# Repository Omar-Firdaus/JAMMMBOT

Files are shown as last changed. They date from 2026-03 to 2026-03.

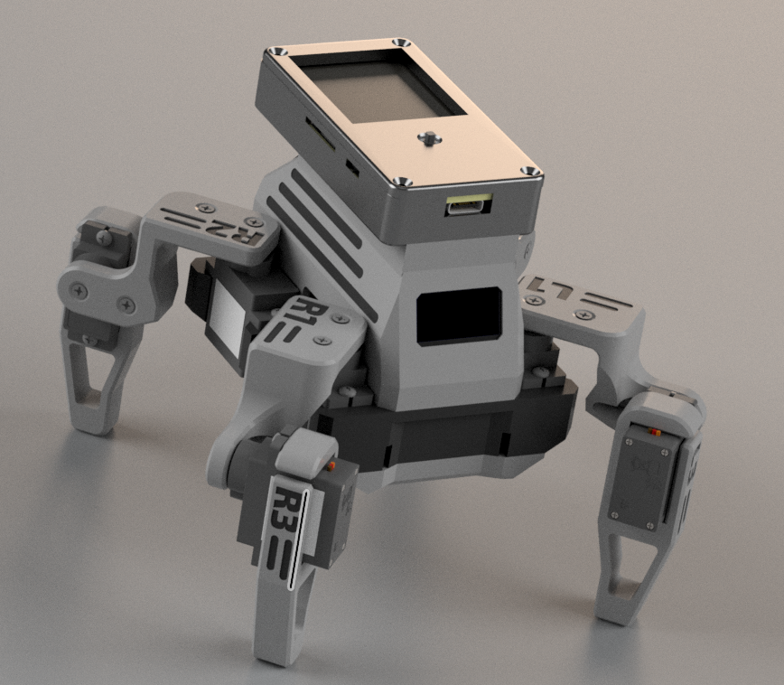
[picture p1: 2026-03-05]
Renders/Screenshot 2026-03-04 at 9.39.10 PM.png

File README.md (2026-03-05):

# JAMMMBOT

Before anything: huge shoutout to Dorian Todd and JustCallMeKoko, their work is the foudnation for this project and I couldn't have done any of this without their repos and guides.

Description: A quadrupedal robot that will detect nearby Wi-Fi devices, disrupt targeted connections, generate numerous spoofed networks, and overwhelm or mislead wireless scanning tools. Built for educational purposes.

Why I made this: I wanted to build a quadrapedal robot that can crawl, but also wanted to make it special in someway. So, I attached hacking hardware so it can penetrate test networks and do other cool things including but not limited to: staging deauthentication attacks, beacon spam, making fake wifi logins to capture credentials, run packet injections, bluetooth spam, and impersonate SSIDs.

Pictures:

Full Robot CAD
Screenshot 2026-03-04 at 9 39 10 PM
Screenshot 2026-03-05 at 9 21 15 AM

PCB for Power Distrubution
Screenshot 2026-03-05 at 9 07 09 AM

Hacking Board
Screenshot 2026-03-05 at 9 25 23 AM

BOM for Entire Project
| Name | Purpose | Cost (USD) | Qty | Total  |
| --- | --- | --- | --- | --- |
| Power distribution board + components | Powering all components | $29.00 | 1 | $29.00 |
| Filament | 3D printed robot frame | $13.99 | 1 | $13.99 |
| Soldering iron kit | Assembly of electronics | $9.99 | 1 | $9.99  |
| Hacking Board PCB + components | ESP32 control electronics | $18.00 | 1 | $18.00 |
| Control PCB Components (LCSC BOM) | All SMD parts for ESP32 board | $6.64 | 1 | $6.64  |
| M2 screw kit | Structural assembly | $6.55 | 1 | $6.55  |
| XT30 female pigtail | Battery connection | $3.50 | 2 | $7.00  |
| 2-slot 10440 Li-ion charger | Charging battery cells | $9.99 | 1 | $9.99  |
| 10440 Li-ion cells | Robot power supply | $2.49 | 4 | $9.96  |
| AAA holder | Battery mounting | $1.59 | 4 | $6.36  |
| Small zip ties | Cable management | $6.98 | 1 | $6.98  |
| 30AWG silicone wire kit | Dense electronics wiring | $10.09 | 1 | $10.09 |
| 22AWG silicone wire kit | Power wiring | $9.99 | 1 | $9.99  |
| Rocker power switch | Main system power | $0.59 | 5 | $2.95  |
| 0.96" SSD1306 OLED | Robot face display | $5.00 | 2 | $10.00 |
| MG90 Servos | Quadruped locomotion | $2.99 | 8 | $23.92 |

BOM for Power Distrubution PCB
| ID | Component | Designators | Footprint | Qty | Manufacturer Part | Manufacturer | Supplier | Supplier Part | Unit Price |
| -- | --- | --- | --- | --- | --- | --- | --- | --- | --- |
| 1  | 22 nF Capacitor | C3, C9, C11 | C0603 | 3 | CL10B223KB8NNNC | Samsung | LCSC | C21122 | $0.004 |
| 2  | 100 nF Capacitor | C4, C8, C10 | C0603 | 3 | CC0603KRX7R9BB104 | Yageo | LCSC | C14663 | $0.002 |
| 3  | 10 nF Capacitor | C5 | C0603 | 1 | C0603B103M500NT | Torch | LCSC | C17702744 | $0.005 |
| 4  | 3.3 µH Inductor | L1 | IND-SMD L7.3-W6.6 | 1 | MHCI06030-3R3M-S8 | Chilisin | LCSC | C285713 | $0.147 |
| 5  | Red LED | LED1 | LED0603-RD | 1 | KT-0603R | KENTO | LCSC | C2286 | $0.007 |
| 6  | 5.1 kΩ Resistor | R1, R5 | R0603 | 2 | 0603WAF5101T5E | UNI-ROYAL | LCSC | C23186 | $0.001 |
| 7  | 56 kΩ Resistor | R2 | R0603 | 1 | 0603WAF5602T5E | UNI-ROYAL | LCSC | C23206 | $0.001 |
| 8  | 10 kΩ Resistor | R3, R4, R8, R9 | R0603 | 4 | RCT0310KJLF | HKR | LCSC | C177337 | — |
| 9  | 3.5 mm 2-Pin Screw Terminal | 5-12V | ScrewTerm-3.5mm-2Pin | 1 | 1984617 | Phoenix Contact | Digi-Key | — | — |
| 10 | JST-XH 4-Pin Connector | JST-XH | JST-XH-4PIN-2.5 | 1 | — | — | — | — | — |
| 11 | Tactile Switch | RESET, BOOT | KEY-SMD L4.0-W3.0 | 2 | HX 3x4x2-2P-1.6N | Hanxia | LCSC | C49234124 | $0.02 |
| 12 | Large Solder Pad | U5, U7 | SOLDERPAD LG | 2 | — | — | — | — | — |
| 13 | 1 µF Capacitor | C1 | C0805 | 1 | AC0805KKX7R9BB105 | Yageo | LCSC | C726584 | $0.035 |
| 14 | 470 µF Capacitor | C7 | Large SMD Cap | 1 | XT470UF25V90RV0111 | KNSCHA | LCSC | C3445244 | $0.128 |
| 15 | Schottky Diode SS34 | D1, D2 | SMA | 2 | SS34 | MDD | LCSC | C8678 | $0.03 |
| 16 | 3-Pin Headers | P1–P8 | 2.54mm Pin Header | 8 | HDR1X8-2.54 | BOOMELE | LCSC | C27438 | $0.088 |
| 17 | ESP32-S3 Module | U1 | ESP32-S3-WROOM-1 | 1 | ESP32-S3-WROOM-1-N16R8 | Espressif | LCSC | C2913202 | $5.613 |
| 18 | 3.3 V LDO Regulator | U2 | SOT-223-3 | 1 | AMS1117-3.3 | AMS | LCSC | C6186 | $0.197 |
| 19 | Buck Converter IC | U3 | SOT-23-6 | 1 | MSTPS563200DDCR | MSKSEMI | LCSC | C49208508 | $0.177 |
| 20 | 10 µF Capacitor | U4 | SMD Electrolytic | 1 | RST10UF25V014 | KNSCHA | LCSC | C4747969 | $0.025 |

BOM For Hacking ESP PCB
| ID | Component | Designator | Package | Qty | Manufacturer Part | Supplier | Unit Price | Total  |
| -- | --- | --- | --- | --- | --- | --- | --- | --- |
| 1  | 22nF capacitor | C3, C9, C11 | 0603 | 3 | CL10B223KB8NNNC | LCSC | $0.004 | $0.012 |
| 2  | 100nF capacitor | C4, C8, C10 | 0603 | 3 | CC0603KRX7R9BB104 | LCSC | $0.002 | $0.006 |
| 3  | 10nF capacitor | C5 | 0603 | 1 | C0603B103M500NT | LCSC | $0.005 | $0.005 |
| 4  | 3.3uH inductor | L1 | SMD | 1 | MHCI06030-3R3M-S8 | LCSC | $0.147 | $0.147 |
| 5  | Red LED | LED1 | 0603 | 1 | KT-0603R | LCSC | $0.007 | $0.007 |
| 6  | 5.1kΩ resistor | R1, R5 | 0603 | 2 | 0603WAF5101T5E | LCSC | $0.001 | $0.002 |
| 7  | 56kΩ resistor | R2 | 0603 | 1 | 0603WAF5602T5E | LCSC | $0.001 | $0.001 |
| 8  | 10kΩ resistor | R3, R4, R8, R9 | 0603 | 4 | RCT0310KJLF | LCSC | ~$0.001 | $0.004 |
| 9  | 3.5mm 2-pin screw terminal | 5-12V input | Through-hole | 1 | 1984617 | Digi-Key | ~$0.50 | $0.50  |
| 10 | JST-XH 4-pin connector | JST-XH | 2.5mm | 1 | JST-XH-4P | LCSC | ~$0.10 | $0.10  |
| 11 | Tactile switch | RESET, BOOT | SMD | 2 | HX 3x4x2-2P | LCSC | $0.02 | $0.04  |
| 12 | Solder pads | U5, U7 | PCB pad | 2 | — | — | — | — |
| 13 | 1µF capacitor | C1 | 0805 | 1 | AC0805KKX7R9BB105 | LCSC | $0.035 | $0.035 |
| 14 | 470µF capacitor | C7 | SMD electrolytic | 1 | XT470UF25V90RV0111 | LCSC | $0.128 | $0.128 |
| 15 | SS34 Schottky diode | D1, D2 | SMA | 2 | SS34 | LCSC | $0.030 | $0.060 |
| 16 | 3-pin headers | P1-P8 | 2.54mm | 8 | HDR1X8-2.54 | LCSC | $0.088 | $0.704 |
| 17 | ESP32-S3-WROOM-1-N16R8 | U1 | RF module | 1 | ESP32-S3-WROOM-1-N16R8 | LCSC | $5.613 | $5.613 |
| 18 | AMS1117-3.3 LDO | U2 | SOT-223 | 1 | AMS1117-3.3 | LCSC | $0.197 | $0.197 |
| 19 | Buck converter IC | U3 | SOT-23-6 | 1 | MSTPS563200DDCR | LCSC | $0.177 | $0.177 |
| 20 | 10µF capacitor | U4 | SMD | 1 | RST10UF25V014 | LCSC | $0.025 | $0.025 |

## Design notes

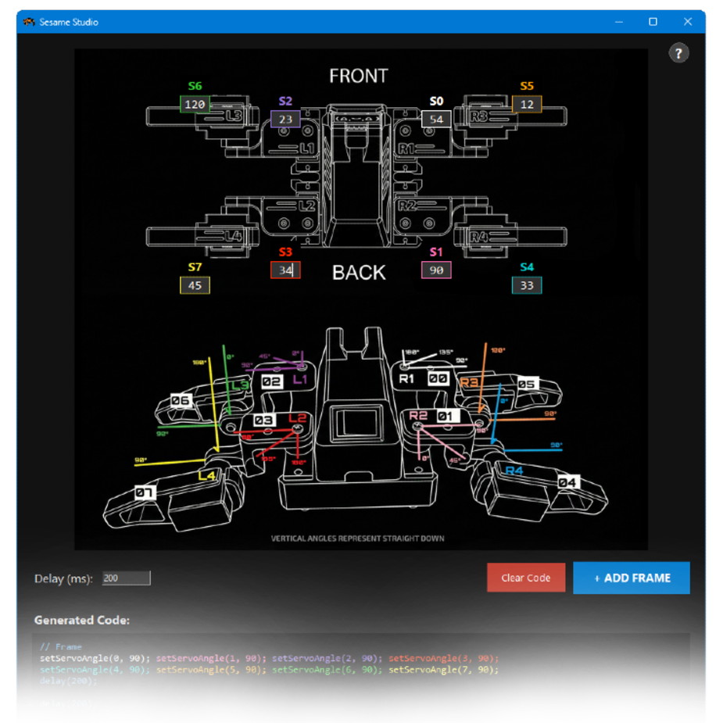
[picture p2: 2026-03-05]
Software/assets/sesamestudio-preview.png

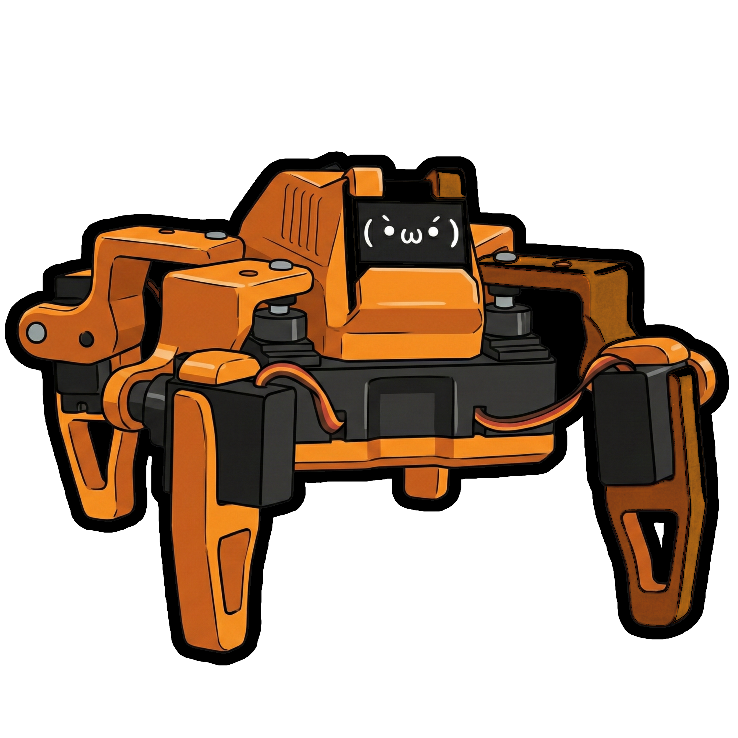
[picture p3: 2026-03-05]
Software/assets/sesame-sticker2.png

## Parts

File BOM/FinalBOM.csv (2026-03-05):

Name | Purpose | Cost (USD) | Qty | Total | Purchase Link
Power distribution board + components | Powering all components | 29.00 | 1 | 29.00 | https://www.pcbway.com/
Filament | 3D printed robot frame | 13.99 | 1 | 13.99 | https://www.amazon.com/ELEGOO-Filament-Dimensional-Accuracy-Cardboard/dp/B0BM739JRF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
Soldering iron kit | Assembly of electronics | 9.99 | 1 | 9.99 | https://www.amazon.com/Soldering-Adjustable-Temperature-356-932%E2%84%89-Electronics/dp/B0FP24CFB9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
Hacking Board PCB + components | ESP32 control electronics | 18.00 | 1 | 18.00 | https://jlcpcb.com/
Control PCB Components (LCSC BOM) | All SMD parts for ESP32 board | 6.64 | 1 | 6.64 | https://jlcpcb.com/
M2 screw kit | Structural assembly | 6.55 | 1 | 6.55 | https://www.amazon.com/Tapping-Woodworking-Fastener-Drilling-Assortment/dp/B0C5JVC6Z3
XT30 female pigtail | Battery connection | 3.50 | 2 | 7.00 | https://www.amazon.com/Padarsey-Connector-Female-Housing-Silicon/dp/B07CZDQT4T?sp_csd=d2lkZ2V0TmFtZT1zcF9hdGY
2-slot 10440 Li-ion charger | Charging battery cells | 9.99 | 1 | 9.99 | https://www.amazon.com/Battery-Bay-Charging-Universal-Batteries/dp/B0FW3JXCMS?sp_csd=d2lkZ2V0TmFtZT1zcF9hdGY
10440 Li-ion cells | Robot power supply | 2.49 | 4 | 9.96 | https://www.amazon.com/Rechargeable-Battery-JESSPOW-Batteries-Flashlight/dp/B08H4RC1Y5
AAA holder | Battery mounting | 1.59 | 4 | 6.36 | https://www.amazon.com/LAMPVPATH-Battery-Holder-Leads-Wires/dp/B08DR6L8F8/ref=sr_1_3?sr=8-3
Small zip ties | Cable management | 6.98 | 1 | 6.98 | https://www.amazon.com/gp/aw/d/B08TVLYB3Q/?aaxitk=bb1635f0ea64a6ea0029127a073b7fc4&hsa_cr_id=0
30AWG silicone wire kit | Dense electronics wiring | 10.09 | 1 | 10.09 | https://www.amazon.com/Fermerry-Silicone-Colors-Flexible-Stranded/dp/B089CXFH4H/ref=sr_1_7?sr=8-7
22AWG silicone wire kit | Power wiring | 9.99 | 1 | 9.99 | https://www.amazon.com/Stranded-Silicone-Electrical-32-8ft-Automotive/dp/B0DK571MVD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
Rocker power switch | Main system power | 0.59 | 5 | 2.95 | https://www.amazon.com/Rierdge-Household-Appliances-Industrial-Equipment/dp/B0F5BFYZSY
0.96 inch SSD1306 OLED | Robot face display | 5.00 | 2 | 10.00 | https://www.amazon.com/Wishiot-Display-Self-Luminous-Compatible-Raspberry/dp/B0D1BWY9Z8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
MG90 Servos | Quadruped locomotion | 2.99 | 8 | 23.92 | https://www.amazon.com/Beffkkip-Helicopter-Servos-Arduino-Project/dp/B01JY3H4MA

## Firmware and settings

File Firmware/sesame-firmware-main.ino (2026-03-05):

#include <WiFi.h>
#include <WebServer.h>
#include <DNSServer.h>
#include <ESPmDNS.h>
#include <Wire.h>
#include <ESP32Servo.h>
#include <Adafruit_GFX.h>
#include <Adafruit_SSD1306.h>
#include "face-bitmaps.h"
#include "movement-sequences.h"
#include "captive-portal.h"

// --- Access Point Configuration ---
// This is the network the Robot will create
#define AP_SSID  "Sesame-Controller-BETA"
#define AP_PASS  "12345678" // Must be at least 8 characters

// --- Station Mode Configuration (Optional) ---
// Set these to connect to your home/office WiFi network
// Leave NETWORK_SSID empty to disable station mode
#define NETWORK_SSID ""  // Your WiFi network name
#define NETWORK_PASS ""  // Your WiFi password
#define ENABLE_NETWORK_MODE false  // Set to true to enable network connection attempts

#define SCREEN_WIDTH 128
#define SCREEN_HEIGHT 64
#define OLED_RESET -1
#define OLED_I2C_ADDR 0x3C

// I2C Pins for Distro Board V2
//#define I2C_SDA 8
//#define I2C_SCL 9

// I2C Pins for Distro Board
//#define I2C_SDA 21
//#define I2C_SCL 22

// I2C Pins for S2 Mini Board
#define I2C_SDA 33
#define I2C_SCL 35


// DNS Server for Captive Portal
DNSServer dnsServer;
const byte DNS_PORT = 53;

Adafruit_SSD1306 display(SCREEN_WIDTH, SCREEN_HEIGHT, &Wire, OLED_RESET);
WebServer server(80);

// Global state for animations
String currentCommand = "";
String currentFaceName = "default";
const unsigned char* const* currentFaceFrames = nullptr;
uint8_t currentFaceFrameCount = 0;
uint8_t currentFaceFrameIndex = 0;
unsigned long lastFaceFrameMs = 0;
int faceFps = 8;
FaceAnimMode currentFaceMode = FACE_ANIM_LOOP;
int8_t faceFrameDirection = 1;
bool faceAnimFinished = false;
int currentFaceFps = 0;
bool idleActive = false;
bool idleBlinkActive = false;
unsigned long nextIdleBlinkMs = 0;
uint8_t idleBlinkRepeatsLeft = 0;

// WiFi Info Scrolling
unsigned long lastInputTime = 0;
bool firstInputReceived = false;
bool showingWifiInfo = false;
int wifiScrollPos = 0;
unsigned long lastWifiScrollMs = 0;
String wifiInfoText = "";

// Network Mode
bool networkConnected = false;
IPAddress networkIP;
String deviceHostname = "sesame-robot";

// Servo Pins for Distro Board
// ======================================================================
// Pin numbers are coorisponding to the ESP32 GPIO pins and may differ based on which board you use.
// If you are using a different board, please adjust the servoPins array accordingly.
// ======================================================================
Servo servos[8];
// Sesame Distro Board V2 Pinout
//const int servoPins[8] = {4, 5, 6, 7, 15, 16, 17, 18};

// Sesame Distro Board Pinout
//const int servoPins[8] = {15, 2, 23, 19, 4, 16, 17, 18};

// Lolin S2 Mini Pinout
const int servoPins[8] = {1, 2, 4, 6, 8, 10, 13, 14};

// Subtrim values for each servo (offset in degrees)
int8_t servoSubtrim[8] = {0, 0, 0, 0, 0, 0, 0, 0};


// Animation constants
int frameDelay = 100;
int walkCycles = 10;
int motorCurrentDelay = 20; // ms delay between motor movements to prevent over-current

struct FaceEntry {
  const char* name;
  const unsigned char* const* frames;
  uint8_t maxFrames;
};

static const uint8_t MAX_FACE_FRAMES = 6;

#define MAKE_FACE_FRAMES(name) \
  const unsigned char* const face_##name##_frames[] = { \
    epd_bitmap_##name, epd_bitmap_##name##_1, epd_bitmap_##name##_2, \
    epd_bitmap_##name##_3, epd_bitmap_##name##_4, epd_bitmap_##name##_5 \
  };

#define X(name) MAKE_FACE_FRAMES(name)
FACE_LIST
#undef X
#undef MAKE_FACE_FRAMES

const FaceEntry faceEntries[] = {
#define X(name) { #name, face_##name##_frames, MAX_FACE_FRAMES },
  FACE_LIST
#undef X
  { "default", face_defualt_frames, MAX_FACE_FRAMES }
};

struct FaceFpsEntry {
  const char* name;
  uint8_t fps;
};

const FaceFpsEntry faceFpsEntries[] = {
  { "walk", 1 },
  { "rest", 1 },
  { "swim", 1 },
  { "dance", 1 },
  { "wave", 1 },
  { "point", 5 },
  { "stand", 1 },
  { "cute", 1 },
  { "pushup", 1 },
  { "freaky", 1 },
  { "bow", 1 },
  { "worm", 1 },
  { "shake", 1 },
  { "shrug", 1 },
  { "dead", 2 },
  { "crab", 1 },
  { "idle", 1 },
  { "idle_blink", 7 },
  { "default", 1 },
  // Conversational faces (manually controlled by Python - no auto-animation)
  { "happy", 1 },
  { "talk_happy", 1 },
  { "sad", 1 },
  { "talk_sad", 1 },
  { "angry", 1 },
  { "talk_angry", 1 },
  { "surprised", 1 },
  { "talk_surprised", 1 },
  { "sleepy", 1 },
  { "talk_sleepy", 1 },
  { "love", 1 },
  { "talk_love", 1 },
  { "excited", 1 },
  { "talk_excited", 1 },
  { "confused", 1 },
  { "talk_confused", 1 },
  { "thinking", 1 },
  { "talk_thinking", 1 },
};


// Prototypes
void setServoAngle(uint8_t channel, int angle);
void updateFaceBitmap(const unsigned char* bitmap);
void setFace(const String& faceName);
void setFaceMode(FaceAnimMode mode);
void setFaceWithMode(const String& faceName, FaceAnimMode mode);
void updateAnimatedFace();
void delayWithFace(unsigned long ms);
void enterIdle();
void exitIdle();
void updateIdleBlink();
int getFaceFpsForName(const String& faceName);
bool pressingCheck(String cmd, int ms);
void handleGetSettings();
void handleSetSettings();
void handleGetStatus();
void handleApiCommand();
void updateWifiInfoScroll();
void recordInput();

void handleRoot() {
  server.send(200, "text/html", index_html);
}

void handleCommandWeb() {
  // We send 200 OK immediately so the web browser doesn't hang waiting for animation to finish
  if (server.hasArg("pose")) {
    currentCommand = server.arg("pose");
    recordInput();
    exitIdle();
    server.send(200, "text/plain", "OK"); 
  } 
  else if (server.hasArg("go")) {
    currentCommand = server.arg("go");
    recordInput();
    exitIdle();
    server.send(200, "text/plain", "OK");
  } 
  else if (server.hasArg("stop")) {
    currentCommand = "";
    recordInput();
    server.send(200, "text/plain", "OK");
  }
  else if (server.hasArg("motor") && server.hasArg("value")) {
    int motorNum = server.arg("motor").toInt();
    int servoIdx = servoNameToIndex(server.arg("motor"));
    int angle = server.arg("value").toInt();
    if (motorNum >= 1 && motorNum <= 8 && angle >= 0 && angle <= 180) {
      setServoAngle(motorNum - 1, angle); // Convert 1-based to 0-based index
      recordInput();
      server.send(200, "text/plain", "OK");
    } else if (servoIdx != -1 && angle >= 0 && angle <= 180) {
      setServoAngle(servoIdx, angle);
      recordInput();
      server.send(200, "text/plain", "OK");
    } else {
      server.send(400, "text/plain", "Invalid motor or angle");
    }
  }
  else {
    server.send(400, "text/plain", "Bad Args");
  }
}

void handleGetSettings() {
  String json = "{";
  json += "\"frameDelay\":" + String(frameDelay) + ",";
  json += "\"walkCycles\":" + String(walkCycles) + ",";
  json += "\"motorCurrentDelay\":" + String(motorCurrentDelay) + ",";
  json += "\"faceFps\":" + String(faceFps);
  json += "}";
  server.send(200, "application/json", json);
}

void handleSetSettings() {
  if (server.hasArg("frameDelay")) frameDelay = server.arg("frameDelay").toInt();
  if (server.hasArg("walkCycles")) walkCycles = server.arg("walkCycles").toInt();
  if (server.hasArg("motorCurrentDelay")) motorCurrentDelay = server.arg("motorCurrentDelay").toInt();
  if (server.hasArg("faceFps")) faceFps = (int)max(1L, server.arg("faceFps").toInt());
  server.send(200, "text/plain", "OK");
}

// API endpoint for network clients to get robot status
void handleGetStatus() {
  String json = "{";
  json += "\"currentCommand\":\"" + currentCommand + "\",";
  json += "\"currentFace\":\"" + currentFaceName + "\",";
  json += "\"networkConnected\":" + String(networkConnected ? "true" : "false") + ",";
  json += "\"apIP\":\"" + WiFi.softAPIP().toString() + "\"";
  if (networkConnected) {
    json += ",\"networkIP\":\"" + networkIP.toString() + "\"";
  }
  json += "}";
  server.send(200, "application/json", json);
}

// API endpoint for network clients to send commands (JSON-based)
void handleApiCommand() {
  if (server.method() != HTTP_POST) {
    server.send(405, "application/json", "{\"error\":\"Method not allowed\"}");
    return;
  }
  
  String body = server.arg("plain");
  
  Serial.println("API Command received:");
  Serial.println(body);
  
  // Check for face-only command (no movement)
  int faceOnlyStart = body.indexOf("\"face\":\"");
  if (faceOnlyStart == -1) {
    faceOnlyStart = body.indexOf("\"face\": \"");
  }
  
  // If we have a face but no command field, it's face-only
  bool faceOnly = (faceOnlyStart > 0 && body.indexOf("\"command\":") == -1 && body.indexOf("\"command\": ") == -1);
  
  String command = "";
  String face = "";
  
  // Parse face
  if (faceOnlyStart > 0) {
    faceOnlyStart = body.indexOf("\"", faceOnlyStart + 6) + 1;
    int faceEnd = body.indexOf("\"", faceOnlyStart);
    if (faceEnd > faceOnlyStart) {
      face = body.substring(faceOnlyStart, faceEnd);
      Serial.print("Parsed face: ");
      Serial.println(face);
    }
  }
  
  // Parse command (if not face-only)
  if (!faceOnly) {
    int cmdStart = body.indexOf("\"command\":\"");
    if (cmdStart == -1) {
      cmdStart = body.indexOf("\"command\": \"");
    }
    
    if (cmdStart == -1) {
      Serial.println("Error: command field not found");
      server.send(400, "application/json", "{\"error\":\"Missing command field\"}");
      return;
    }
    
    cmdStart = body.indexOf("\"", cmdStart + 10) + 1;
    int cmdEnd = body.indexOf("\"", cmdStart);
    
    if (cmdEnd <= cmdStart) {
      Serial.println("Error: invalid command format");
      server.send(400, "application/json", "{\"error\":\"Invalid command format\"}");
      return;
    }
    
    command = body.substring(cmdStart, cmdEnd);
    Serial.print("Parsed command: ");
    Serial.println(command);
  }
  
  // Set face if provided
  if (face.length() > 0) {
    setFace(face);
  }
  
  // If face-only, just acknowledge
  if (faceOnly) {
    recordInput();
    server.send(200, "application/json", "{\"status\":\"ok\",\"message\":\"Face updated\"}");
    return;
  }
  
  // Execute command
  if (command == "stop") {
    currentCommand = "";
    recordInput();
    server.send(200, "application/json", "{\"status\":\"ok\",\"message\":\"Command stopped\"}");
  } else {
    currentCommand = command;
    recordInput();
    exitIdle();
    server.send(200, "application/json", "{\"status\":\"ok\",\"message\":\"Command executed\"}");
  }
}

void setup() {
  Serial.begin(115200);
  randomSeed(micros());
  
  // I2C Init for ESP32
  Wire.begin(I2C_SDA, I2C_SCL);

  // OLED Init
  if (!display.begin(SSD1306_SWITCHCAPVCC, OLED_I2C_ADDR)) {
    Serial.println(F("SSD1306 allocation failed."));
    while (1);
  }
  
  display.clearDisplay();
  display.setTextColor(SSD1306_WHITE);
  display.setTextSize(1);
  display.setCursor(0,0);
  display.println(F("Setting up WiFi..."));
  display.display();

  // --- WIFI CONFIGURATION ---
  // Try to connect to network first if configured
  if (ENABLE_NETWORK_MODE && String(NETWORK_SSID).length() > 0) {
    Serial.println("Attempting to connect to network: " + String(NETWORK_SSID));
    WiFi.mode(WIFI_AP_STA); // Enable both AP and Station modes
    WiFi.setHostname(deviceHostname.c_str());
    WiFi.begin(NETWORK_SSID, NETWORK_PASS);
    
    // Wait up to 10 seconds for connection
    int attempts = 0;
    while (WiFi.status() != WL_CONNECTED && attempts < 20) {
      delay(500);
      Serial.print(".");
      attempts++;
    }
    
    if (WiFi.status() == WL_CONNECTED) {
      networkConnected = true;
      networkIP = WiFi.localIP();
      Serial.println();
      Serial.print("Connected to network! IP: ");
      Serial.println(networkIP);
    } else {
      Serial.println();
      Serial.println("Failed to connect to network. Running in AP-only mode.");
      WiFi.mode(WIFI_AP); // Fall back to AP-only
    }
  } else {
    WiFi.mode(WIFI_AP);
    Serial.println("Network mode disabled. Running in AP-only mode.");
  }
  
  // --- ACCESS POINT CONFIGURATION ---
  WiFi.softAP(AP_SSID, AP_PASS);
  IPAddress myIP = WiFi.softAPIP();
  
  Serial.print("AP Created. IP: ");
  Serial.println(myIP);

  // Build WiFi info text for scrolling
  if (networkConnected) {
    wifiInfoText = "AP: " + String(AP_SSID) + " (" + myIP.toString() + ")  |  Network: " + String(NETWORK_SSID) + " (" + networkIP.toString() + ") or " + deviceHostname + ".local  |  ";
  } else {
    wifiInfoText = "Connect to WiFi: " + String(AP_SSID) + "  |  Pass: " + String(AP_PASS) + "  |  IP: " + myIP.toString() + "  |  Captive Portal will auto-open!  |  ";
  }
  
  // Initialize input tracking
  lastInputTime = millis();
  firstInputReceived = false;
  showingWifiInfo = false;

  // Start mDNS responder for local network discovery
  if (MDNS.begin(deviceHostname.c_str())) {
    Serial.println("mDNS responder started");
    Serial.print("Access controller at: http://");
    Serial.print(deviceHostname);
    Serial.println(".local");
    MDNS.addService("http", "tcp", 80);
  } else {
    Serial.println("Error setting up mDNS responder!");
  }

  // Start DNS Server for Captive Portal
  // This redirects ALL domain requests to the ESP32's IP
  dnsServer.start(DNS_PORT, "*", myIP);

  // Web Server Routes
  server.on("/", handleRoot);
  server.on("/cmd", handleCommandWeb);
  server.on("/getSettings", handleGetSettings);
  server.on("/setSettings", handleSetSettings);
  
  // API endpoints for network communication
  server.on("/api/status", handleGetStatus);
  server.on("/api/command", handleApiCommand);
  
  // Catch-all route for captive portal
  // This ensures any URL redirects to the controller page
  server.onNotFound(handleRoot);
  
  server.begin();

  // PWM Init
  ESP32PWM::allocateTimer(0);
  ESP32PWM::allocateTimer(1);
  ESP32PWM::allocateTimer(2);
  ESP32PWM::allocateTimer(3);
  
  for (int i = 0; i < 8; i++) {
    servos[i].setPeriodHertz(50);
    // Map 0-180 to approx 732-2929us
    servos[i].attach(servoPins[i], 732, 2929);
  }
  delay(10);
  
  // Show rest face on startup without moving motors
  setFace("rest");
  
  Serial.println(F("HTTP server & Captive Portal started."));
}

void loop() {
  // Process DNS requests for captive portal
  dnsServer.processNextRequest();
  
  server.handleClient();
  updateAnimatedFace();
  updateIdleBlink();
  updateWifiInfoScroll();

  if (currentCommand != "") {
    String cmd = currentCommand;
    if (cmd == "forward") runWalkPose();
    else if (cmd == "backward") runWalkBackward();
    else if (cmd == "left") runTurnLeft();
    else if (cmd == "right") runTurnRight();
    else if (cmd == "rest") { runRestPose(); if (currentCommand == "rest") currentCommand = ""; }
    else if (cmd == "stand") { runStandPose(1); if (currentCommand == "stand") currentCommand = ""; }
    else if (cmd == "wave") runWavePose();
    else if (cmd == "dance") runDancePose();
    else if (cmd == "swim") runSwimPose();
    else if (cmd == "point") runPointPose();
    else if (cmd == "pushup") runPushupPose();
    else if (cmd == "bow") runBowPose();
    else if (cmd == "cute") runCutePose();
    else if (cmd == "freaky") runFreakyPose();
    else if (cmd == "worm") runWormPose();
    else if (cmd == "shake") runShakePose();
    else if (cmd == "shrug") runShrugPose();
    else if (cmd == "dead") runDeadPose();
    else if (cmd == "crab") runCrabPose();
  }
  
  // Serial CLI for debugging (can be used to diagnose servo position issues and wiring)
  if (Serial.available()) {
    static char command_buffer[32];
    static byte buffer_pos = 0;
    char c = Serial.read();
    if (c == '\n' || c == '\r') {
      if (buffer_pos > 0) {
        command_buffer[buffer_pos] = '\0';
        int motorNum, angle;
        recordInput();
        if(strcmp(command_buffer, "run walk") == 0 || strcmp(command_buffer, "rn wf") == 0) { currentCommand = "forward"; runWalkPose(); currentCommand = ""; }
        else if(strcmp(command_buffer, "rn wb") == 0) { currentCommand = "backward"; runWalkBackward(); currentCommand = ""; }
        else if(strcmp(command_buffer, "rn tl") == 0) { currentCommand = "left"; runTurnLeft(); currentCommand = ""; }
        else if(strcmp(command_buffer, "rn tr") == 0) { currentCommand = "right"; runTurnRight(); currentCommand = ""; }
        else if(strcmp(command_buffer, "run rest") == 0 || strcmp(command_buffer, "rn rs") == 0) runRestPose();
        else if(strcmp(command_buffer, "run stand") == 0 || strcmp(command_buffer, "rn st") == 0) runStandPose(1);
        else if(strcmp(command_buffer, "rn wv") == 0) { currentCommand = "wave"; runWavePose(); }
        else if(strcmp(command_buffer, "rn dn") == 0) { currentCommand = "dance"; runDancePose(); }
        else if(strcmp(command_buffer, "rn sw") == 0) { currentCommand = "swim"; runSwimPose(); }
        else if(strcmp(command_buffer, "rn pt") == 0) { currentCommand = "point"; runPointPose(); }
        else if(strcmp(command_buffer, "rn pu") == 0) { currentCommand = "pushup"; runPushupPose(); }
        else if(strcmp(command_buffer, "rn bw") == 0) { currentCommand = "bow"; runBowPose(); }
        else if(strcmp(command_buffer, "rn ct") == 0) { currentCommand = "cute"; runCutePose(); }
        else if(strcmp(command_buffer, "rn fk") == 0) { currentCommand = "freaky"; runFreakyPose(); }
        else if(strcmp(command_buffer, "rn wm") == 0) { currentCommand = "worm"; runWormPose(); }
        else if(strcmp(command_buffer, "rn sk") == 0) { currentCommand = "shake"; runShakePose(); }
        else if(strcmp(command_buffer, "rn sg") == 0) { currentCommand = "shrug"; runShrugPose(); }
        else if(strcmp(command_buffer, "rn dd") == 0) { currentCommand = "dead"; runDeadPose(); }
        else if(strcmp(command_buffer, "rn cb") == 0) { currentCommand = "crab"; runCrabPose(); }
        else if (strcmp(command_buffer, "subtrim") == 0 || strcmp(command_buffer, "st") == 0) {
          Serial.println("Subtrim values:");
          for (int i = 0; i < 8; i++) {
            Serial.print("Motor "); Serial.print(i); Serial.print(": ");
            if (servoSubtrim[i] >= 0) Serial.print("+");
            Serial.println(servoSubtrim[i]);
          }
        }
        else if (strcmp(command_buffer, "subtrim save") == 0 || strcmp(command_buffer, "st save") == 0) {
          Serial.println("Copy and paste this into your code:");
          Serial.print("int8_t servoSubtrim[8] = {");
          for (int i = 0; i < 8; i++) {
            Serial.print(servoSubtrim[i]);
            if (i < 7) Serial.print(", ");
          }
          Serial.println("};");
        }
        else if (strncmp(command_buffer, "subtrim reset", 13) == 0 || strncmp(command_buffer, "st reset", 8) == 0) {
          for (int i = 0; i < 8; i++) servoSubtrim[i] = 0;
          Serial.println("All subtrim values reset to 0");
        }
        else if (strncmp(command_buffer, "subtrim ", 8) == 0 || strncmp(command_buffer, "st ", 3) == 0) {
          const char* params = (command_buffer[1] == 't') ? command_buffer + 3 : command_buffer + 8;
          int trimMotor, trimValue;
          if (sscanf(params, "%d %d", &trimMotor, &trimValue) == 2) {
            if (trimMotor >= 0 && trimMotor < 8) {
              if (trimValue >= -90 && trimValue <= 90) {
                servoSubtrim[trimMotor] = trimValue;
                Serial.print("Motor "); Serial.print(trimMotor); Serial.print(" subtrim set to ");
                if (trimValue >= 0) Serial.print("+");
                Serial.println(trimValue);
              } else {
                Serial.println("Subtrim value must be between -90 and +90");
              }
            } else {
              Serial.println("Invalid motor number (0-7)");
            }
          }
        }
        else if (strncmp(command_buffer, "all ", 4) == 0) {
             if (sscanf(command_buffer + 4, "%d", &angle) == 1) {
                 for (int i = 0; i < 8; i++) setServoAngle(i, angle);
                 Serial.print("All servos set to "); Serial.println(angle);
             }
        }
        else if (sscanf(command_buffer, "%d %d", &motorNum, &angle) == 2) {
             if (motorNum >= 0 && motorNum < 8) {
                 setServoAngle(motorNum, angle);
                 Serial.print("Servo "); Serial.print(motorNum); Serial.print(" set to "); Serial.println(angle);
             } else {
                 Serial.println("Invalid motor number (0-7)");
             }
        }
        buffer_pos = 0;
      }
    } else if (buffer_pos < sizeof(command_buffer) - 1) {
      command_buffer[buffer_pos++] = c;
    }
  }
}

// Function to update the robot's face
void updateFaceBitmap(const unsigned char* bitmap) {
  display.clearDisplay();
  display.drawBitmap(0, 0, bitmap, 128, 64, SSD1306_WHITE);
  display.display();
}

uint8_t countFrames(const unsigned char* const* frames, uint8_t maxFrames) {
  if (frames == nullptr || frames[0] == nullptr) return 0;
  uint8_t count = 0;
  for (uint8_t i = 0; i < maxFrames; i++) {
    if (frames[i] == nullptr) break;
    count++;
  }
  return count;
}
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
